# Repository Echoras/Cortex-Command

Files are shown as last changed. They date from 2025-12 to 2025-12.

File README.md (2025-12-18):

# Cortex-Command
<p align="center">
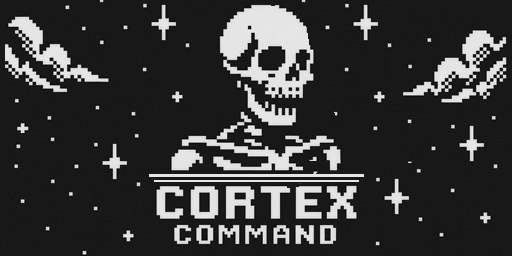
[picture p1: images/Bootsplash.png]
Cortex Command
  
</p>

A DIY **USB MIDI foot controller** built on the **Arduino Pro Micro (ATmega32U4)** — featuring **6 footswitches**, **dual OLED status screens**, and a **TRS expression (wah) input**.

> Goal: a rugged, stage-friendly controller that speaks native USB MIDI and feels like a real piece of gear, not a science fair project.

<table align="center">
  <tr>
    <td align="center">
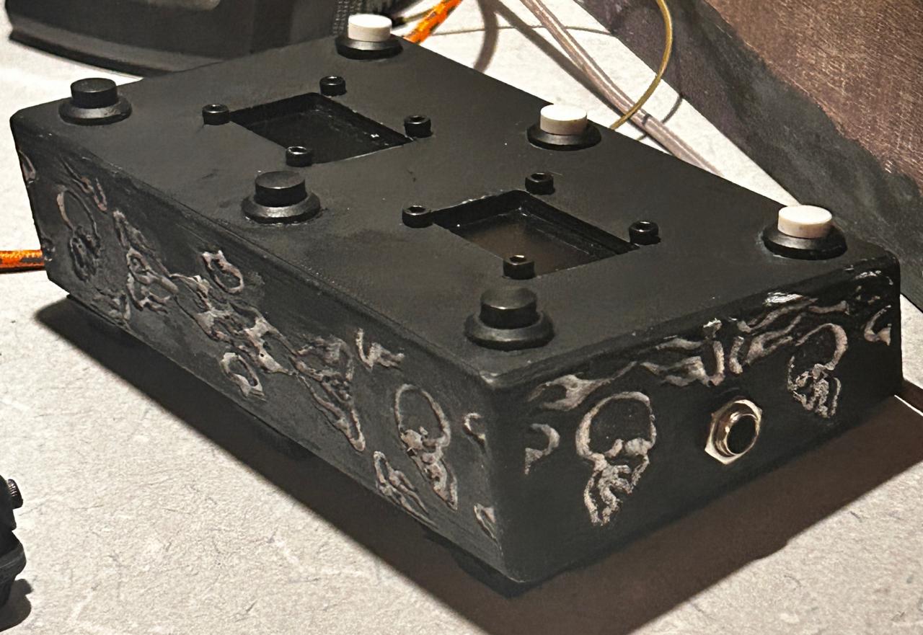
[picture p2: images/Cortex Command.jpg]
Cortex Command - Main controller
      
    </td>
    <td align="center">
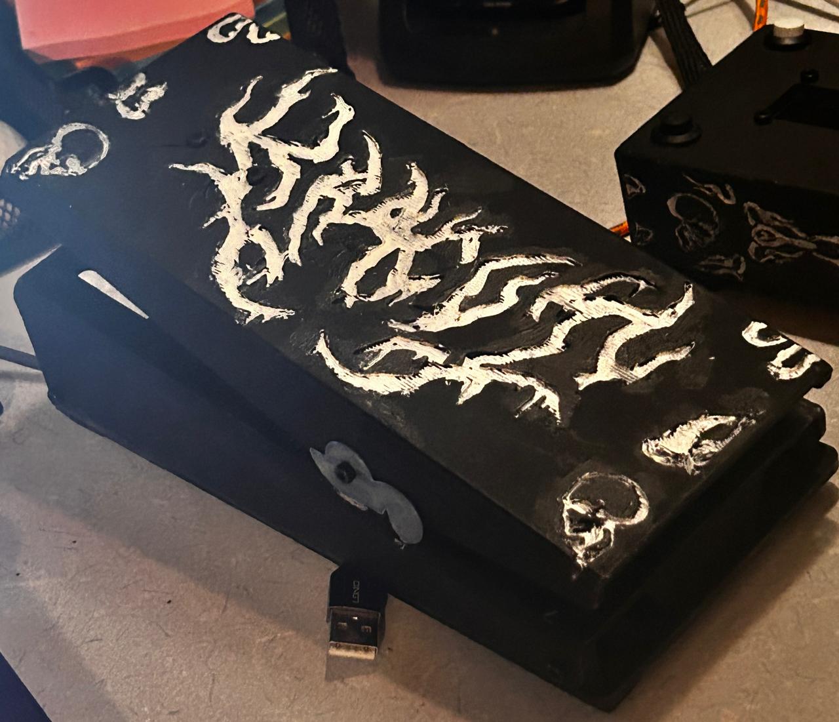
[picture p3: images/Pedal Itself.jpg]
Cortex Command - Expression pedal
      
    </td>
  </tr>
</table>

---
## CREDITS TO:
Adafruit Midi Expression Pedal Overview, i sourced their 3d files for the foot pedal and made lots of changes to it. Code needed to be done in C++ since I was using a different microcontroller.
https://learn.adafruit.com/midi-foot-pedal/
---

## Features
- **Native USB MIDI** via ATmega32U4 (no extra MIDI interface needed)
- **6 momentary footswitches** (INPUT_PULLUP wiring)
- **2× 1.3" I2C OLED displays** (shared bus, different I2C addresses)
- **Expression pedal input** over **TRS** (Tip = 5V, Ring = signal, Sleeve = GND)
- Modular build: main controller + separate expression pedal enclosure (3D FILES ARE INCLUDED /3D files)

---

## Project Gallery / Build Snapshots

**Main controller enclosure**

- Top view / pedal-style layout            - Bottom view / component layout  

    <td align="center">
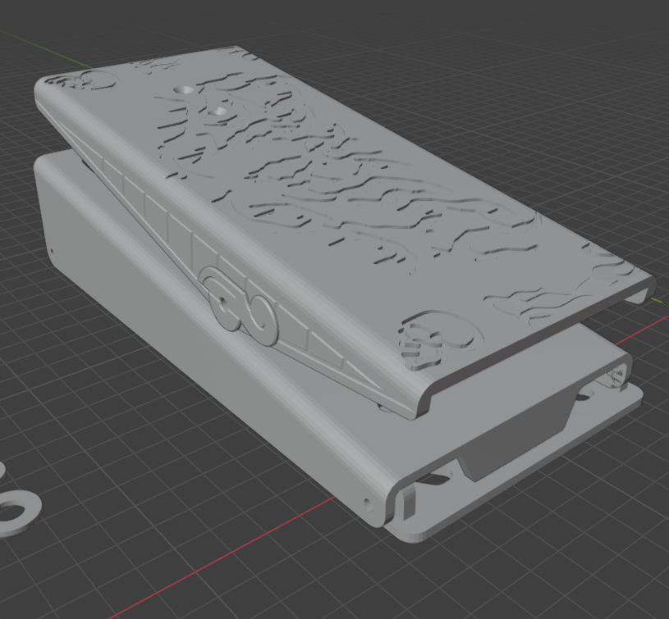
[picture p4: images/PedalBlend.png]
      
    </td>
    <td align="center">
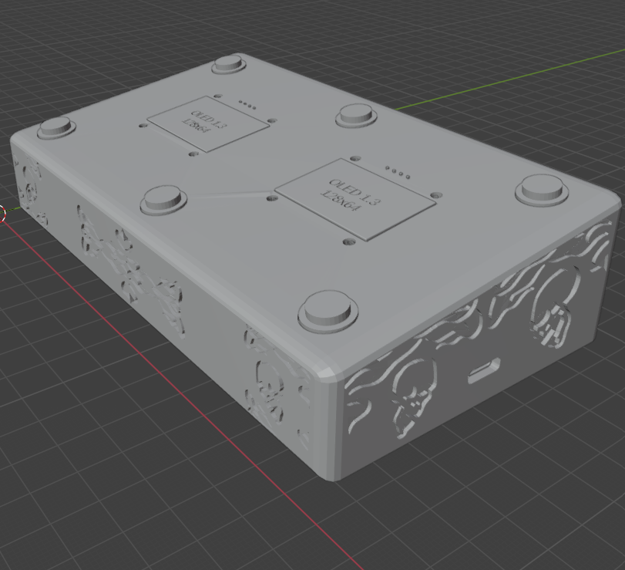
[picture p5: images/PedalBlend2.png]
      
    </td>
  </tr>
</table>

---

## Bill of Materials (BOM)

| Qty | Part |
|---:|---|
| 6 | 12mm Momentary Push Button (SPST, ON/OFF) |
| 2 | TRS 1/4" Female Jack |
| 1 | 1/4" cable (3 ft) |
| — | Dupont wires |
| 2 | 1.3" OLED I2C 128×64 (SH1106 / “12864”) |
| — | Assorted M3 screws |
| 1 | Arduino Pro Micro (ATmega32U4, USB-C) |
| 1 | WH148 Type B10K linear potentiometer (expression pedal) |

---

## Hardware Wiring (Fritzing Diagrams)

This section documents the **final physical wiring** of Cortex Command using Fritzing diagrams.
All images are stored locally in the `/images` directory and reflect the exact build.

---

## OLED Displays (Dual I2C)

Two 1.3" OLED displays are connected on a shared I2C bus.

**Connections**
- SDA → D2  
- SCL → D3  
- VCC → 5V  
- GND → GND  

⚠️ Each display must have a **unique I2C address**:
- Display 1 → `0x3C`
- Display 2 → `0x3D`

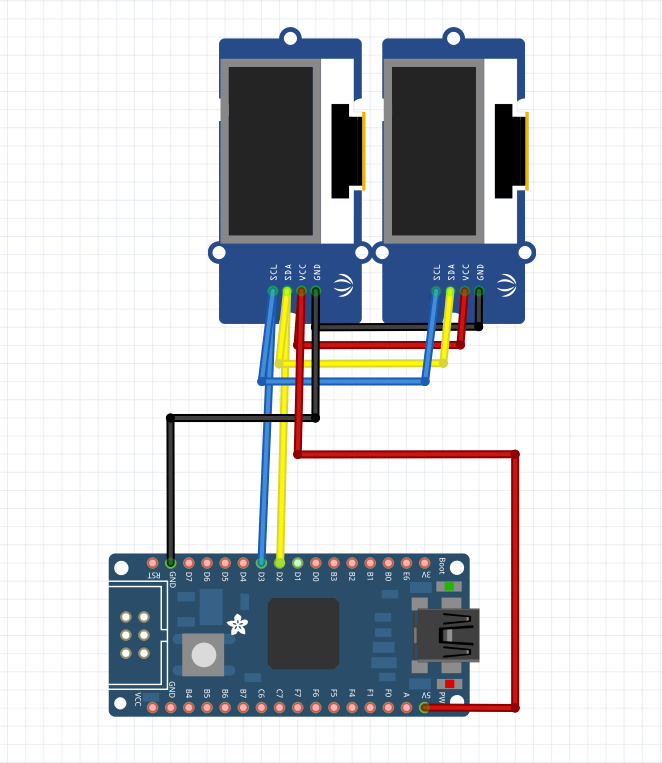
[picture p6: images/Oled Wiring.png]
OLED Wiring Diagram


---

## Expression / Wah Pedal (TRS)

The expression pedal connects via a **1/4\" TRS jack** and uses a B10K linear potentiometer
configured as a voltage divider.

**TRS Mapping**
- Tip → +5V (VCC)
- Ring → Analog Signal (A0)
- Sleeve → Ground (GND)

This allows the pedal to output a stable **0–5V signal** into analog pin A0.

(FOR OVERALL EXPRESSION PEDAL ASSEMBLY ITS WELL DOCUMENTED IN THE ADAFRUIT WEBSITE: https://learn.adafruit.com/midi-foot-pedal/)

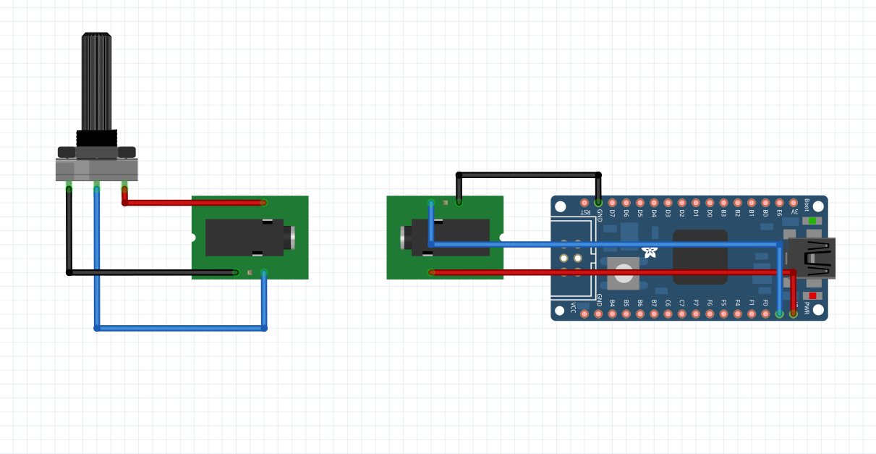
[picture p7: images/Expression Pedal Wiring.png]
Expression Pedal Wiring Diagram


---

## Footswitches (6× Momentary Buttons)

All six footswitches use the Arduino `INPUT_PULLUP` configuration.

**Wiring Method**
- One terminal → Digital input pin
- One terminal → Common GND
- Pressed = LOW

**Pin Assignments**
| Button | Pin | MIDI CC |
|---:|-----|---|
| 1 | D4 | CC 101 |
| 2 | D6 | CC 102 |
| 3 | D7 | CC 103 |
| 4 | D8 | CC 104 |
| 5 | D9 | CC 105 |
| 6 | D10 | CC 106 |

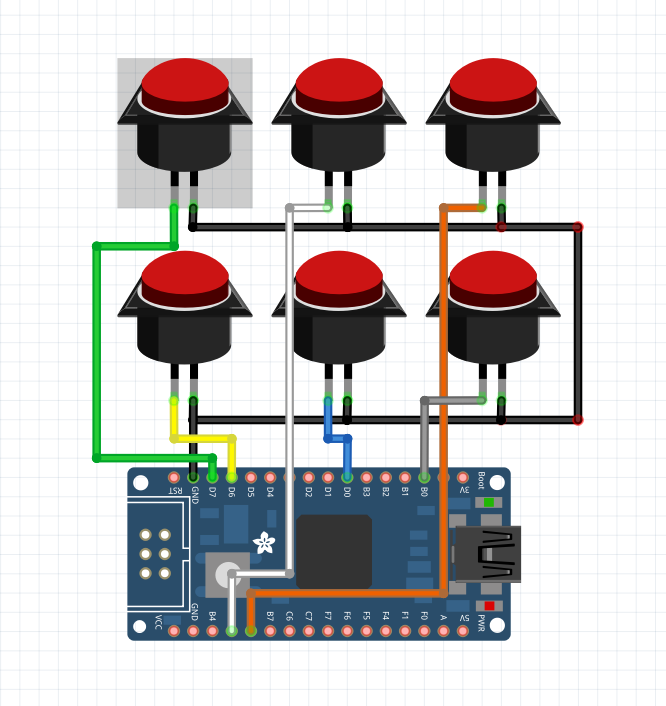
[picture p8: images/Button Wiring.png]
Button Wiring Diagram


---

## Firmware

The Arduino sketch handling:
- USB MIDI
- Button scanning + debouncing
- Expression pedal analog input
- OLED rendering

is located here:

 **[`/firmware/sketch_midi.ino`](firmware/sketch_midi.ino)**

(Requires an Arduino Pro Micro / ATmega32U4 for native USB MIDI support.)

---

## Notes
- All grounds are tied to a **single common GND**
- OLED instability usually indicates:
  - Incorrect I2C address
  - SDA/SCL swapped
  - Weak USB power source
 
<h2 align="center">Display Demo</h2>

<p align="center">
  <a href="images/Display%20Video.mp4">▶ Watch the display demo (MP4)</a>
</p>

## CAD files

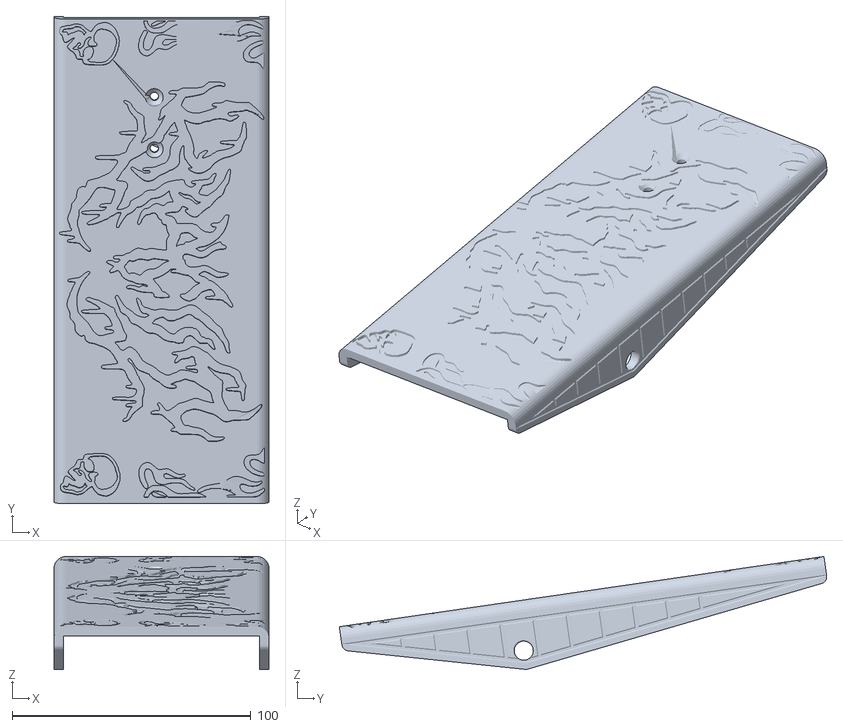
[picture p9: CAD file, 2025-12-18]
3D files/mohamed_top-pedal mod.stl
90.0 x 204.1 x 47.3

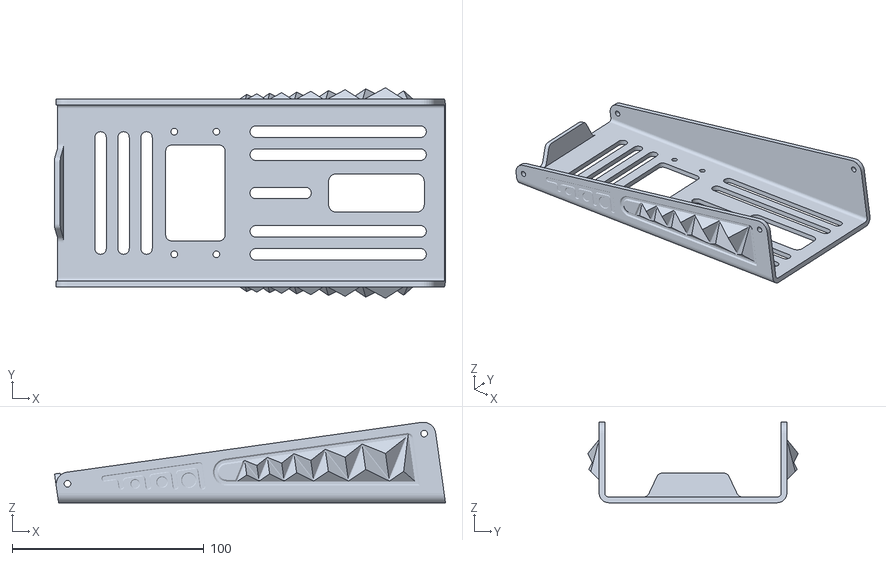
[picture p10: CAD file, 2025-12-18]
3D files/Base-Frame.stl
204.1 x 109.9 x 42.0

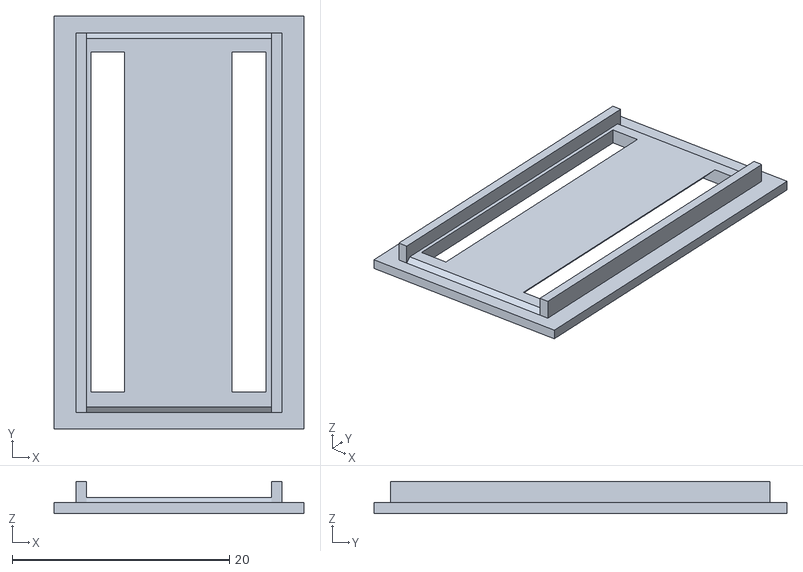
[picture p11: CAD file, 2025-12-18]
3D files/Topfinal.stl
23.0 x 38.0 x 2.97

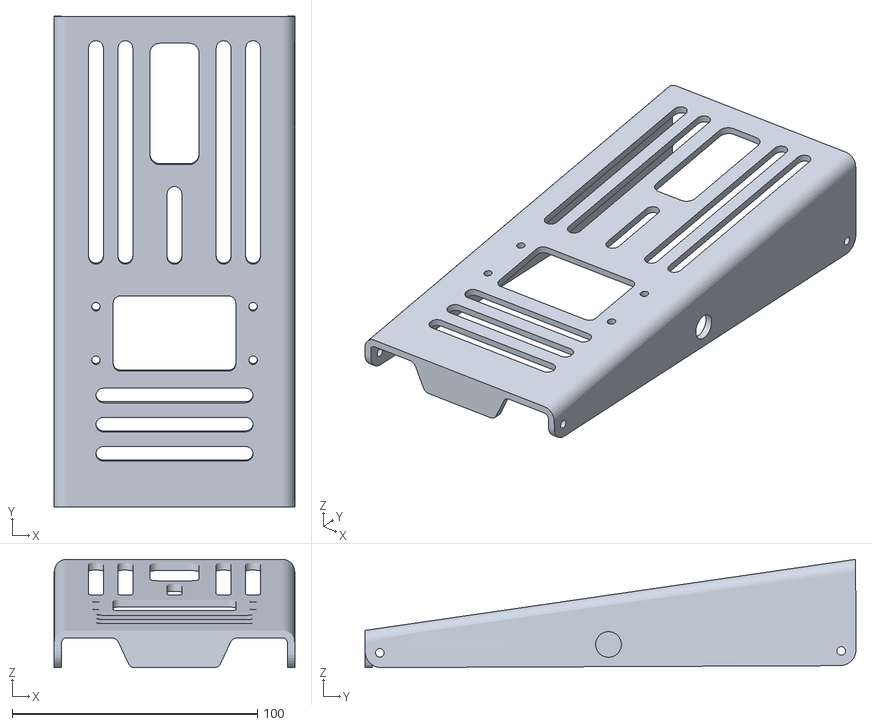
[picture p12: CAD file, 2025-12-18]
3D files/mohamed_base-frame mod.stl
98.0 x 200.0 x 44.1

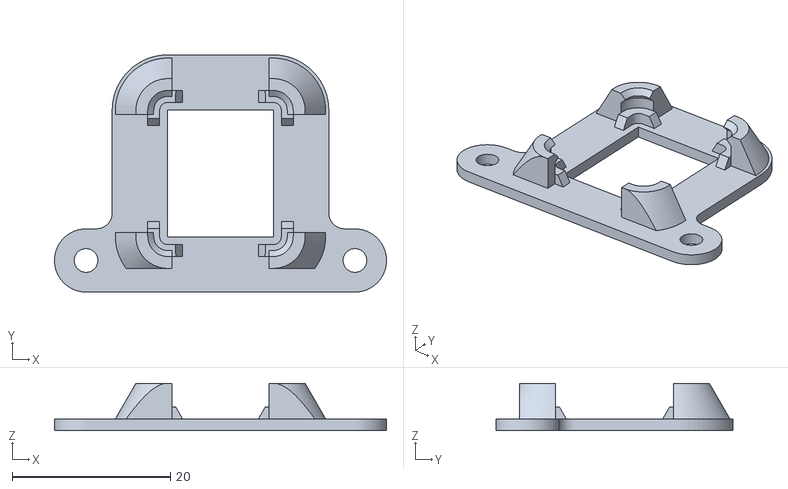
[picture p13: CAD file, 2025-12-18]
3D files/QTPy-Holder.stl
42.0 x 30.0 x 6.00

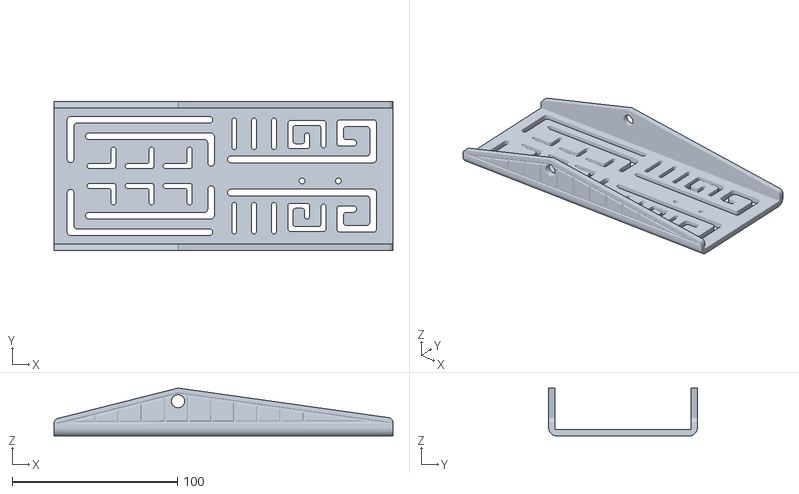
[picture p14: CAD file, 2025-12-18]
3D files/Top-Pedal.stl
205.0 x 90.0 x 29.0

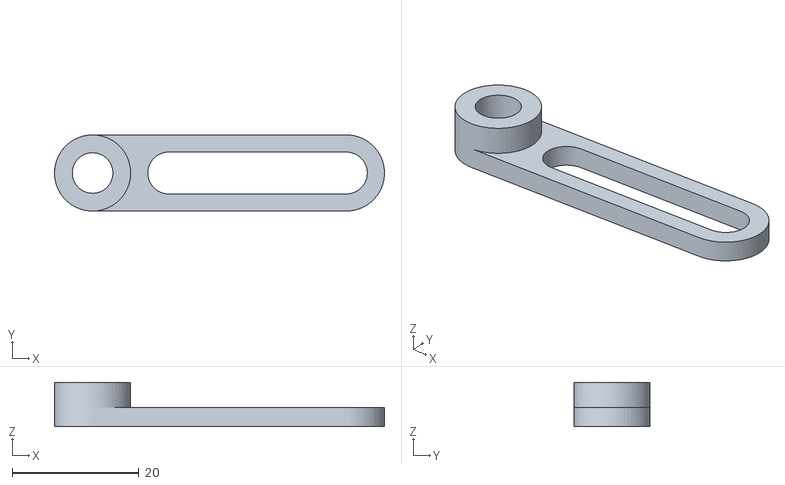
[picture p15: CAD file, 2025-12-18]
3D files/Pot-Linkage.stl
52.0 x 12.0 x 7.00

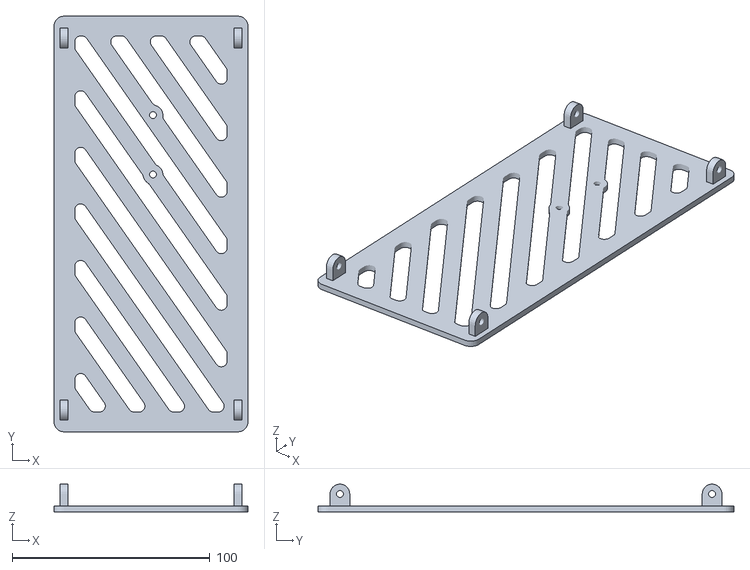
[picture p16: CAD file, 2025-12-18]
3D files/mohamed_bottom plate mod.stl
98.0 x 210.0 x 14.0

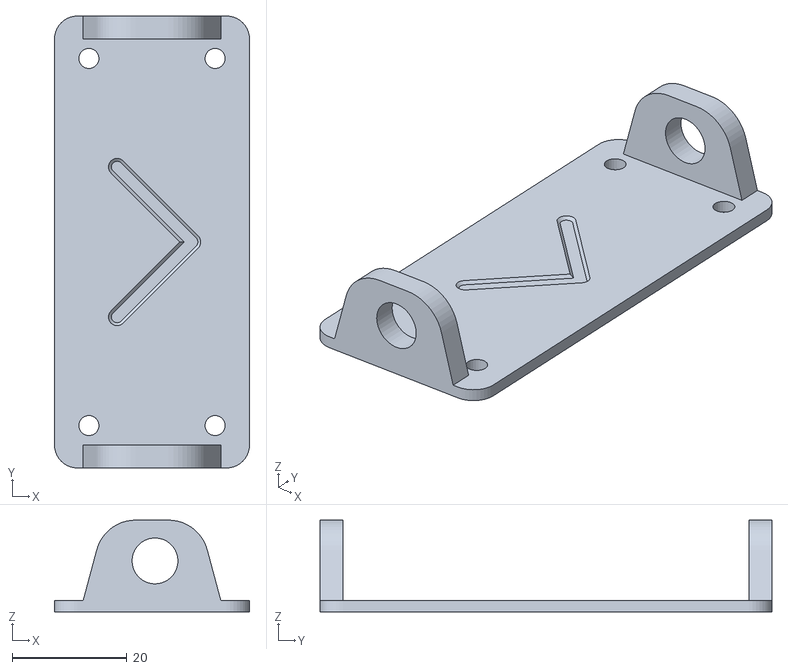
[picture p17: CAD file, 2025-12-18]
3D files/Hinge-Plate.stl
34.0 x 78.8 x 16.0

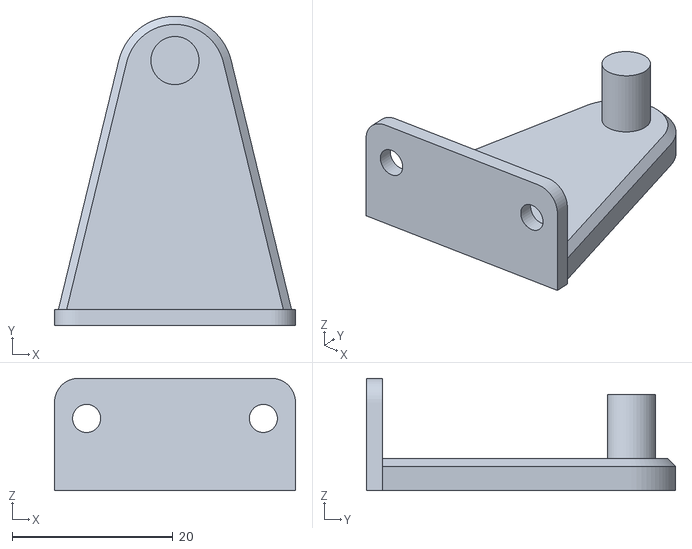
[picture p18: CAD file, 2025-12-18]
3D files/Pedal-Arm.stl
30.0 x 38.5 x 14.0

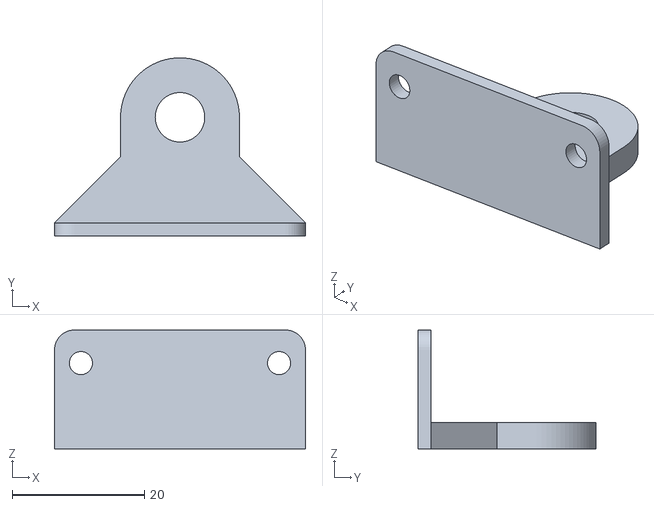
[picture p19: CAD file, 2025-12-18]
3D files/Pot-Holder.stl
38.0 x 27.0 x 18.0

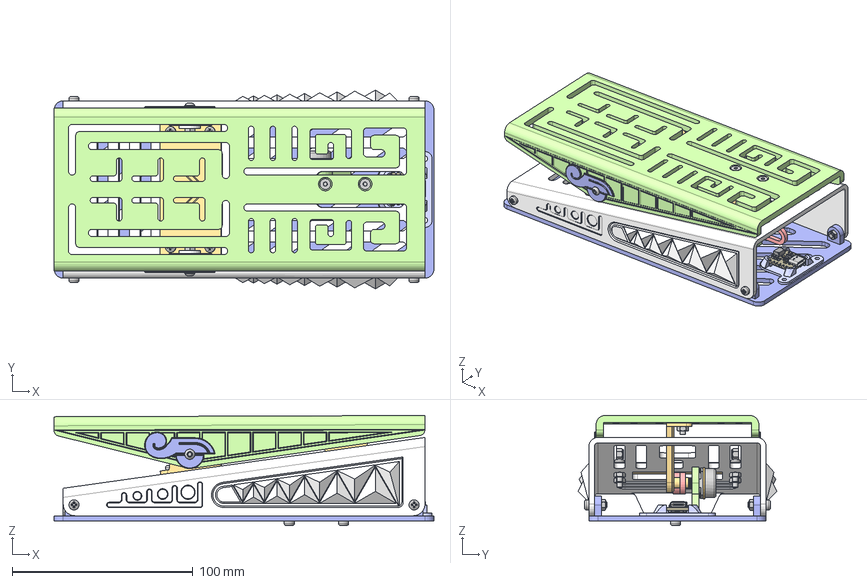
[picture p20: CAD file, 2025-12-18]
3D files/MIDI_Foot_Pedal.step
210.1 x 109.9 x 60.9 mm
Bottom Plate
Bottom Frame
Top Pedal
Hinge Bracket
10K Potentiometer
Board
10uF x 2
STEMMA_I2C_QTSKINNY
AP2112K-3.3
WS2812B_SK6805_1515
NSR0320 x 2
8MB QSPI Flash
1K x 17
1uF x 3
USB Type C
RP2040_QFN56
KMR2 x 2
12MHZ
Pot Holder
Pot Linkage
Pedal Arm
M3x16mm x 2
M3 locknut x 2
m3x10mm flat head x 2
m3 hex nut x 2
m3x10mm (1) x 4
M3 nuts x 4
m3 nut x 2
m3x10mm x 2
m3 nut(Mirror) x 2
m3x10mm(Mirror) x 2
m3 x 10mm x 2
m3 nut (1) x 2
sleeve washer (1)
inner washer
sleeve washer (1) (1)
inner washer (1)

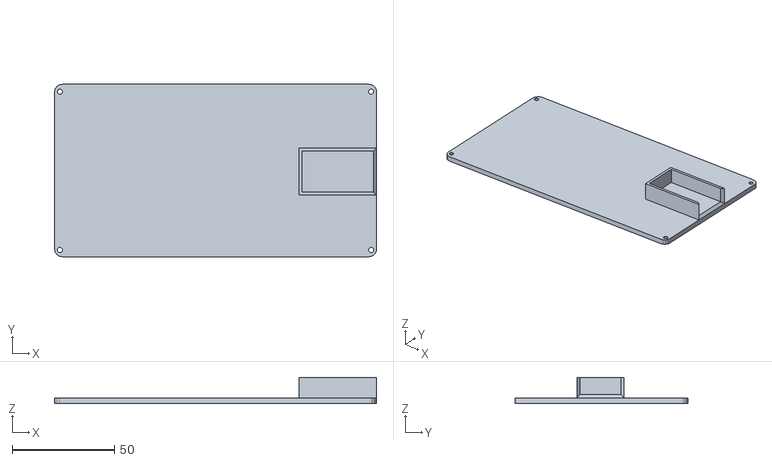
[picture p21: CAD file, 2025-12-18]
3D files/mohamed_bot.stl
157.4 x 84.3 x 12.9

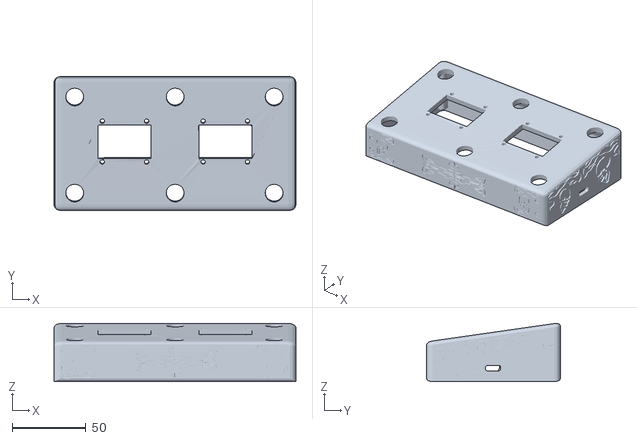
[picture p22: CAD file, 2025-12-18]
3D files/mohamed_Top.stl
163.8 x 90.5 x 39.4

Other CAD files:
3D files/Bottom-Plate.stl
3D files/washer-middle.stl
3D files/washer-sleeve-a.stl
3D files/washer-sleeve-b.stl
3D files/MIDI_Foot_Pedal.f3z
3D files/washer-cap.stl

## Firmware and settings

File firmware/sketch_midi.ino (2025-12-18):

#include <MIDIUSB.h>
#include <U8g2lib.h>
#include <Wire.h>

U8G2_SH1106_128X64_NONAME_F_HW_I2C screenA(U8G2_R0, U8X8_PIN_NONE); // Plugins
U8G2_SH1106_128X64_NONAME_F_HW_I2C screenB(U8G2_R0, U8X8_PIN_NONE); // Presets

// 'Bootsplash', 128x64px
const unsigned char epd_bitmap_Bootsplash [] PROGMEM = {
	0x00, 0x00, 0x00, 0x00, 0x00, 0x00, 0x00, 0x00, 0x00, 0x00, 0x00, 0x00, 0x00, 0x00, 0x00, 0x00, 
	0x00, 0x00, 0x00, 0x00, 0x10, 0x00, 0x00, 0x80, 0x3f, 0x00, 0x40, 0x08, 0x00, 0x00, 0x00, 0x00, 
	0x00, 0x00, 0x00, 0x00, 0x00, 0x01, 0x00, 0xe0, 0xff, 0x00, 0x00, 0x08, 0x00, 0x00, 0x00, 0x00, 
	0x00, 0x00, 0x00, 0x00, 0x00, 0x01, 0x00, 0xf8, 0xff, 0x01, 0x00, 0x08, 0x00, 0x00, 0x00, 0x00, 
	0x70, 0x00, 0x00, 0x00, 0x00, 0x03, 0x00, 0xfc, 0xff, 0x03, 0x00, 0x08, 0x00, 0x00, 0x00, 0x00, 
	0xf8, 0x00, 0x00, 0x00, 0x80, 0x07, 0x00, 0xfe, 0xff, 0x07, 0x00, 0x1c, 0x00, 0x00, 0x00, 0x00, 
	0xfc, 0x01, 0x00, 0x00, 0x80, 0x07, 0x00, 0xfe, 0xff, 0x0f, 0x00, 0x1c, 0x00, 0x00, 0x00, 0x00, 
	0xe0, 0x03, 0x00, 0x00, 0x00, 0x03, 0x00, 0xff, 0xff, 0x1f, 0x00, 0x08, 0x00, 0x00, 0x00, 0x00, 
	0xc0, 0x07, 0x00, 0x00, 0x00, 0x00, 0x00, 0x7f, 0xff, 0x1f, 0x00, 0x08, 0x00, 0x00, 0xc0, 0x03, 
	0x80, 0x07, 0x00, 0x00, 0x00, 0x00, 0x80, 0x7f, 0xff, 0x1f, 0x00, 0x08, 0x00, 0x00, 0xe0, 0x07, 
	0x40, 0x07, 0x00, 0x02, 0x00, 0x00, 0x80, 0x7f, 0xfe, 0x1f, 0x00, 0x00, 0x00, 0x00, 0xf0, 0x27, 
	0x82, 0x73, 0x00, 0x00, 0x00, 0x00, 0x80, 0x3f, 0xfe, 0x1f, 0x00, 0x00, 0x02, 0x00, 0xf0, 0x39, 
	0x06, 0xfb, 0x00, 0x00, 0x00, 0x00, 0x80, 0x1f, 0x83, 0x37, 0x00, 0x00, 0x00, 0x00, 0xf0, 0x12, 
	0x06, 0xfe, 0x01, 0x00, 0x00, 0x00, 0x00, 0x0f, 0x81, 0x23, 0x00, 0x00, 0x00, 0x00, 0x70, 0x00, 
	0x0e, 0xfe, 0x01, 0x00, 0x00, 0x00, 0x00, 0x86, 0x81, 0x03, 0x00, 0x00, 0x00, 0x00, 0x63, 0x01, 
	0x1c, 0xd8, 0x03, 0x00, 0x00, 0x00, 0x00, 0x81, 0x81, 0x23, 0x00, 0x00, 0x00, 0x80, 0xa7, 0x70, 
	0x5a, 0xa0, 0x01, 0x00, 0x00, 0x00, 0x00, 0x83, 0xc1, 0x05, 0x00, 0x00, 0x40, 0xc0, 0x6f, 0x38, 
	0xf4, 0x40, 0x3d, 0x00, 0x00, 0x00, 0x00, 0xce, 0xe3, 0x14, 0x40, 0x00, 0x00, 0xe0, 0xff, 0x1c, 
	0x88, 0x81, 0x7f, 0x00, 0x00, 0x00, 0x00, 0xf0, 0xf7, 0x38, 0x00, 0x00, 0x00, 0xe0, 0x3d, 0x2c, 
	0x80, 0x03, 0xe1, 0x01, 0x00, 0x00, 0x00, 0x80, 0x7f, 0x3a, 0x00, 0x00, 0x00, 0xe0, 0x58, 0x0c, 
	0x00, 0x0e, 0x00, 0x00, 0x00, 0x00, 0x00, 0x08, 0xf9, 0x1f, 0x00, 0x00, 0x00, 0xe0, 0x00, 0x09, 
	0x00, 0x78, 0x00, 0x00, 0x00, 0x00, 0x00, 0x28, 0xfc, 0x0f, 0x00, 0x00, 0x00, 0x6f, 0x81, 0x0f, 
	0x00, 0xe0, 0x01, 0x00, 0x00, 0x00, 0x00, 0x60, 0xa8, 0x0a, 0x00, 0x00, 0x80, 0xb7, 0xb0, 0x03, 
	0x00, 0x00, 0x00, 0x00, 0x00, 0x10, 0x00, 0x40, 0xb8, 0x0f, 0x00, 0x40, 0xe0, 0x03, 0x78, 0x01, 
	0x00, 0x00, 0x00, 0x00, 0x00, 0x18, 0x00, 0xc0, 0x00, 0x00, 0x00, 0xc0, 0x00, 0x00, 0x1e, 0x00, 
	0x00, 0x00, 0x00, 0x00, 0x00, 0x00, 0x00, 0xc0, 0x00, 0x00, 0x00, 0x00, 0x00, 0x80, 0x07, 0x00, 
	0x00, 0x00, 0x00, 0x00, 0x00, 0x00, 0x00, 0xc0, 0x15, 0x00, 0x00, 0x00, 0x00, 0x00, 0x00, 0x00, 
	0x00, 0x00, 0x00, 0x00, 0x00, 0x00, 0x00, 0x80, 0x93, 0x02, 0x00, 0x00, 0x00, 0x00, 0x00, 0x00, 
	0x00, 0x00, 0x00, 0x00, 0x02, 0x00, 0x00, 0x10, 0xdf, 0x02, 0x00, 0x00, 0x00, 0x00, 0x00, 0x00, 
	0x00, 0x10, 0x00, 0x00, 0x00, 0x00, 0x00, 0x30, 0xfe, 0x03, 0x00, 0x00, 0x00, 0x00, 0x00, 0x08, 
	0x00, 0x00, 0x00, 0x00, 0x00, 0x00, 0x00, 0x00, 0xf8, 0x03, 0x00, 0x00, 0x40, 0x00, 0x00, 0x00, 
	0x20, 0x00, 0x00, 0x00, 0x00, 0x00, 0x00, 0x44, 0x00, 0x00, 0x00, 0x00, 0x00, 0x00, 0x00, 0x00, 
	0x60, 0x00, 0x00, 0x00, 0x00, 0x00, 0x00, 0xe7, 0x01, 0x00, 0x00, 0x00, 0x00, 0x00, 0x20, 0x00, 
	0x00, 0x00, 0x00, 0x00, 0x00, 0x00, 0x80, 0x81, 0x01, 0x00, 0x00, 0x00, 0x00, 0x00, 0x20, 0x00, 
	0x00, 0x00, 0x00, 0x00, 0x00, 0x80, 0xcf, 0x01, 0x80, 0x87, 0x03, 0x00, 0x00, 0x00, 0x20, 0x00, 
	0x00, 0x00, 0x00, 0x00, 0x00, 0xc0, 0x3f, 0xe0, 0x00, 0xe4, 0x07, 0x00, 0x00, 0x00, 0x60, 0x00, 
	0x10, 0x00, 0x00, 0x10, 0x00, 0x00, 0x80, 0x07, 0x00, 0x38, 0x00, 0x00, 0x00, 0x00, 0xf8, 0x01, 
	0x00, 0x00, 0x00, 0x10, 0x00, 0xe0, 0x01, 0xfc, 0x8f, 0x0f, 0x1e, 0x00, 0x00, 0x00, 0x60, 0x00, 
	0x00, 0x00, 0x00, 0x10, 0x00, 0xf0, 0x03, 0xc0, 0x9f, 0x01, 0x1c, 0x00, 0x00, 0x00, 0x00, 0x00, 
	0x00, 0x00, 0x00, 0x30, 0x00, 0xf8, 0xe7, 0x00, 0xf8, 0x40, 0x1c, 0x00, 0x00, 0x00, 0x00, 0x00, 
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
};

// 'Skull', 20x20px
const unsigned char Skull [] PROGMEM = {
	0xe0, 0x7f, 0x00, 0x1c, 0x80, 0x03, 0x1c, 0x80, 0x03, 0x0c, 0x00, 0x03, 0x06, 0x00, 0x06, 0xf6, 
	0xf0, 0x06, 0xfd, 0xf9, 0x0b, 0xfd, 0xf9, 0x0b, 0xfd, 0xf9, 0x0b, 0xfd, 0xf9, 0x0b, 0xf1, 0xf0, 
	0x08, 0x07, 0x06, 0x0e, 0x0f, 0x06, 0x0f, 0x0e, 0x06, 0x07, 0x1c, 0x80, 0x03, 0x90, 0x99, 0x00, 
	0x90, 0x99, 0x00, 0xf0, 0xff, 0x00, 0xe0, 0x7f, 0x00, 0x00, 0x00, 0x00
};
//Feather
const unsigned char Feather [] PROGMEM = {
	0x00, 0xa0, 0x07, 0x00, 0xb0, 0x05, 0x00, 0xf2, 0x07, 0x00, 0x76, 0x06, 0x00, 0xb7, 0x01, 0x80, 
	0xd7, 0x07, 0xe0, 0xee, 0x03, 0xe0, 0xfe, 0x03, 0xe0, 0x36, 0x00, 0xe8, 0xfc, 0x01, 0xe8, 0x60, 
	0x00, 0x78, 0x3f, 0x00, 0xf8, 0x3f, 0x00, 0xb8, 0x1f, 0x00, 0xe8, 0x00, 0x00, 0xf4, 0x07, 0x00, 
	0x0c, 0x00, 0x00, 0x03, 0x00, 0x00, 0x02, 0x00, 0x00, 0x00, 0x00, 0x00
};
//Buttersfly
const unsigned char Butterfly [] PROGMEM = {
	0x00, 0x38, 0x00, 0x00, 0x38, 0x00, 0x00, 0x6c, 0x00, 0x40, 0xec, 0x00, 0x40, 0xdc, 0x00, 0x8c, 
	0xc4, 0x01, 0x10, 0x35, 0x01, 0x00, 0x95, 0x00, 0x00, 0xf7, 0x03, 0xf0, 0x3f, 0x06, 0x1e, 0x1d, 
	0x04, 0x77, 0x1c, 0x04, 0xd7, 0xf7, 0x06, 0x1e, 0x77, 0x07, 0x78, 0x73, 0x00, 0x60, 0x23, 0x00, 
	0xc0, 0x22, 0x00, 0x00, 0x3e, 0x00, 0x00, 0x3c, 0x00, 0x00, 0x00, 0x00
};

const unsigned char* pluginIcons[3] = {
  Skull,     // GOJIRA
  Feather,   // CORY WONG
  Butterfly  // PLINI
};

void showBootSplash() {
  // Screen A
  screenA.clearBuffer();
  screenA.drawXBMP(0, 0, 128, 64, epd_bitmap_Bootsplash);
  screenA.sendBuffer();

  // Screen B
  screenB.clearBuffer();
  screenB.drawXBMP(0, 0, 128, 64, epd_bitmap_Bootsplash);
  screenB.sendBuffer();

  delay(1500); // show for 1.5 seconds
}

  // Animation state
  unsigned long lastBlink = 0;
  bool blinkState = true;  // whether the ">" arrow is visible

  unsigned long lastVibrate = 0;
  bool vibrateActive = false;
  int vibrateOffset = 0;




// ============================================================
//  OLED DISPLAYS
// ============================================================

// Active selections
int activePlugin = 0;     // 0=Gojira, 1=Cory, 2=Plini
int currentPreset = -1;   // -1 = none yet selected

// Display names
const char* pluginNames[3] = {
  "GOJIRA",
  "CORY WONG",
  "PLINI"
};

const char* presetNames[3] = {
  "PRESET #1",
  "PRESET #2",
  "PRESET #3"
};


// ============================================================
//  EXPRESSION PEDAL (Wah)
// ============================================================
const int potPin = A0;
int potMin = 0;
int potMax = 234;
const int wahCC = 1;  // CC1 = Wah
int lastCC = -1;


// ============================================================
//  BUTTONS
// ============================================================
// Plugin switching buttons (4, 5, 6)
const int pluginButtons[3] = {4, 5, 6};
int lastPluginState[3] = {HIGH, HIGH, HIGH};
int pluginCC[3] = {20, 21, 22};   // CC20/21/22 for plugin switching

// Preset switching buttons (7, 8, 9)
const int presetButtons[3] = {7, 8, 9};
int lastPresetState[3] = {HIGH, HIGH, HIGH};
int presetPC[3] = {0, 1, 2};      // Preset Program Changes


// ============================================================
//  MIDI HELPERS
// ============================================================
void sendCC(byte cc, byte value) {
  midiEventPacket_t event = {0x0B, 0xB0, cc, value};
  MidiUSB.sendMIDI(event);
}

void sendPC(byte program) {
  midiEventPacket_t event = {0x0C, 0xC0, program, 0};
  MidiUSB.sendMIDI(event);
}


// ============================================================
//  DRAW UI ON SCREENS
// ============================================================
void updateScreens() {

  // ----- LEFT SCREEN (Plugins) -----
  screenB.clearBuffer();
  screenB.setFont(u8g2_font_7x13_tr);
  screenB.drawFrame(0, 0, 128, 64);

  // Icon vibrate offset
  int xOffset = vibrateActive ? vibrateOffset : 0;

  screenB.drawXBMP(108 + xOffset, 0, 20, 20, pluginIcons[activePlugin]);
  screenB.drawStr(5, 13, "PLUGINS:");

  for (int i = 0; i < 3; i++) {
    int y = 28 + i * 14;
    const char* text = pluginNames[i];

    int textWidth = screenB.getStrWidth(text);
    int x = (128 - textWidth) / 2;

    if (i == activePlugin && blinkState) {
      screenB.drawStr(2, y - 2, ">");  // Blinking arrow
    }

    screenB.drawStr(x, y, text);
  }

  screenB.sendBuffer();


  // ----- RIGHT SCREEN (Presets) -----
  screenA.clearBuffer();
  screenA.setFont(u8g2_font_7x13_tr);
  screenA.drawFrame(0, 0, 128, 64);
  screenA.drawXBMP(108 + xOffset, 0, 20, 20, pluginIcons[activePlugin]);

  screenA.drawStr(5, 13, "PRESETS:");

  for (int i = 0; i < 3; i++) {
    int y = 28 + i * 14;
    const char* text = presetNames[i];

    int textWidth = screenA.getStrWidth(text);
    int x = (128 - textWidth) / 2;

    if (i == currentPreset && blinkState) {
      screenA.drawStr(2, y - 2, ">");  // blinking arrow
    }

    screenA.drawStr(x, y, text);
  }

  screenA.sendBuffer();
}



// ============================================================
//  SETUP
// ============================================================
void setup() {
  // Assign correct I2C addresses BEFORE ANY DRAWING
  screenA.setI2CAddress(0x3C * 2); // left screen
  screenB.setI2CAddress(0x3D * 2); // right screen

  screenA.begin();
  screenB.begin();

  showBootSplash(); 


  // Buttons
  for (int i = 0; i < 3; i++) {
    pinMode(pluginButtons[i], INPUT_PULLUP);
    pinMode(presetButtons[i], INPUT_PULLUP);
  }

  updateScreens();  // Draw initial UI
}


// ============================================================
//  MAIN LOOP
// ============================================================
void loop() {
  // ---------------- BLINKING ARROW ----------------
  if (millis() - lastBlink > 350) {
    blinkState = !blinkState;
    lastBlink = millis();
    updateScreens();
  }

  // ---------------- ICON VIBRATION ----------------
  if (vibrateActive && millis() - lastVibrate > 20) {
    vibrateOffset = (vibrateOffset == 1 ? -1 : 1); // jitter
    lastVibrate = millis();
    updateScreens();
  }


  // ---------------- EXPRESSION PEDAL ----------------
  int raw = analogRead(potPin);
  raw = constrain(raw, potMin, potMax);
  int ccValue = map(raw, potMin, potMax, 127, 0);

  if (abs(ccValue - lastCC) > 1) {
    sendCC(wahCC, ccValue);
    lastCC = ccValue;
  }


  // ---------------- PLUGIN SWITCHING BUTTONS (4-6) ----------------
  for (int i = 0; i < 3; i++) {
    int state = digitalRead(pluginButtons[i]);

    if (state == LOW && lastPluginState[i] == HIGH) {
      activePlugin = i;
      sendCC(pluginCC[i], 127);
      updateScreens();
    }

    lastPluginState[i] = state;
  }


  // ---------------- PRESET SWITCHING BUTTONS (7-9) ----------------
  for (int i = 0; i < 3; i++) {
    int state = digitalRead(presetButtons[i]);

    if (state == LOW && lastPresetState[i] == HIGH) {
      sendPC(presetPC[i]);
      currentPreset = i;
      updateScreens();
    }

    lastPresetState[i] = state;
  }

  MidiUSB.flush();
  delay(3);
}
